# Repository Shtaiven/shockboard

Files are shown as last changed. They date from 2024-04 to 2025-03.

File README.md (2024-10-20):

# restive.engines Keyboards

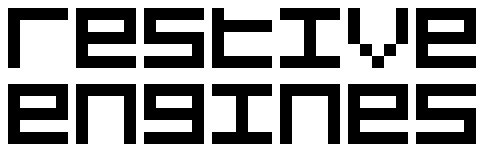
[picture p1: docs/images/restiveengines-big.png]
restiveengines_logo


## Introduction

This repository contains design and manufacturing files created by Steven Eisinger (@Shtaiven a.k.a. restive.engines). Everything you need to manufacture one of my keyboards can be found here, including pcbs, cases, and certain keycaps.

For keyboard firmware, please refer to my [ZMK config repo](https://github.com/Shtaiven/shockboard-zmk-config).

## Keyboards

### fairyboard

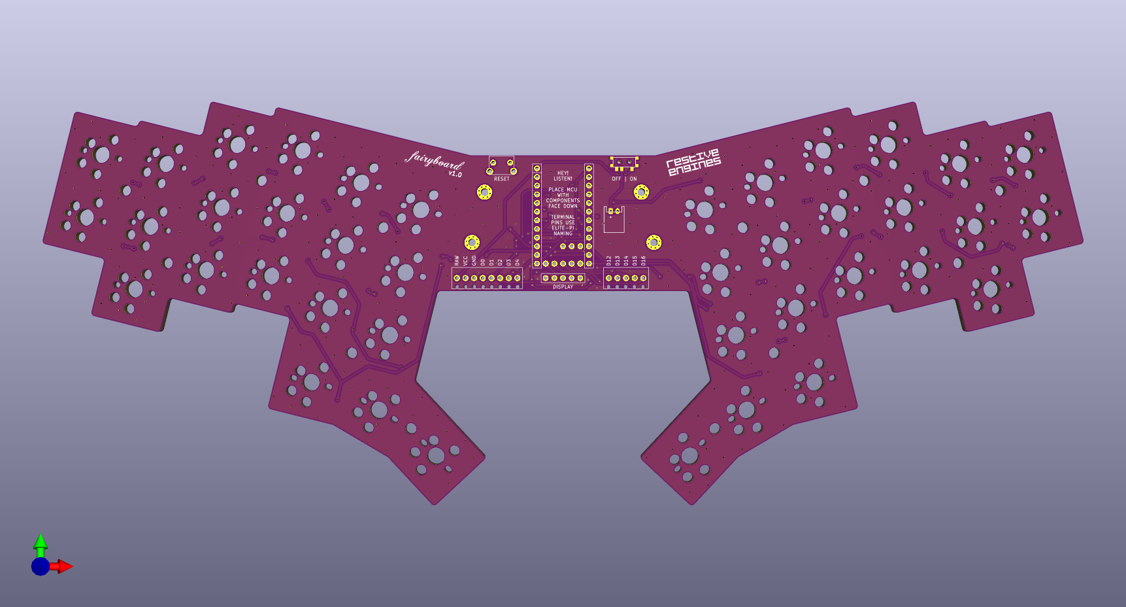
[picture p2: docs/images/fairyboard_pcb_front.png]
fairyboard pcb front


[Build guide](docs/fairyboard.md)

Designed in 2024. Made to address shortcomings and enhance ergonomics of the shockboard. Ergonomic column staggered keyboard extendable with custom modules using terminal blocks or headers. 14 degree rotation on each half. Compatible with MX, Choc v1, and Choc v2 switches.

### shockboard

shockboard_v1_assembled

[Build guide](docs/shockboard.md)

Designed in 2023. My first custom keyboard. Ergonomic column staggered keyboard with a number row, compatible with 1.25u thumb keys. 10 degree rotation on each half. Compatible with MX and Choc v1 switches.

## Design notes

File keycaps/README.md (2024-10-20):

# Printable Keycaps

This folder contains some printable keycaps

## Chicago stenographer

The `chicago_stenographer` directory contains kailh choc v1 keycaps originally designed by @pseudoku and modified by @sporkus and @infused-kim. The stls in this directory are the ones you need to print to get every possible keycap for the fairyboard. Print one of each.

See their original repositories for more info:

* [infused-kim's repo](https://github.com/infused-kim/kb_keycaps_chicago_stenographer)
* [sporkus's repo](https://github.com/sporkus/PseudoMakeMeKeyCapProfiles)
* [pseudoku's repo](https://github.com/pseudoku/PseudoMakeMeKeyCapProfiles)

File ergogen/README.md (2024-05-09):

# Ergogen configuration files

This folder contains the input and ouputs of ergogen to generate the shockboard layout.

## Note on compatibility

Ergogen v4.0.0 introduced breaking changes to configuration. Config files will only work with ergogen >= v4.0.0.

## Generating layouts

Due to the use of custom footprints, [ergogen](ergogen.xyz) must be installed locally and the online versions can't be used.
Before running anything below, ensure [npm](https://docs.npmjs.com/downloading-and-installing-node-js-and-npm) is installed on your system.

```shell
npm install -g ergogen@4
```

Output folders and are generated by calling ergogen in one of the revision folders e.g.

```shell
cd ergogen/shockboard_v1
ergogen .
```

The unrouted pcbs can then be found in the `output/pcbs` folder.

## Generating STLs

The ergogen config generates some cases in jscad format. Before converting these to STL files [jscad/cli](https://github.com/jscad/OpenJSCAD.org) must be installed.

```shell
npm install -g @jscad/cli
```

To generate the STLs, run the following from one of the revision folders (e.g. `shockboard_v1`)

```shell
for i in output/cases/*.jscad; do npx @jscad/cli@1 "$i" -of stla; done
```

The STLs can then be found in the `outpud/cases` folder.

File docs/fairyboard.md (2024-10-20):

# fairyboard

fairyboard pcb front
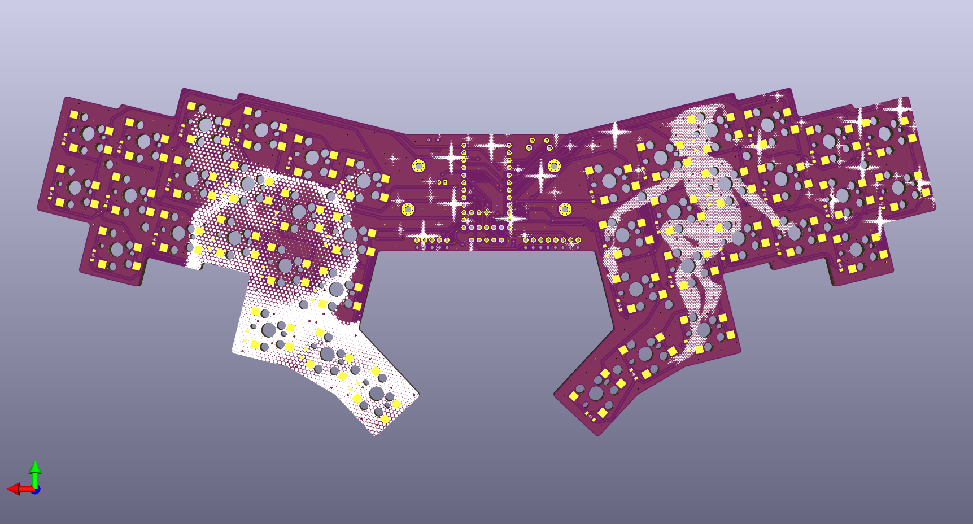
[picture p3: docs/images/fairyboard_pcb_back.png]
fairyboard pcb front


## Introduction

The fairyboard is a monoblock split columnar-staggered keyboard inspired by boards such as the corne, Lily58, Le Chiffre, and others. It is designed based on my own finger positions, with a thumb cluster that is comfortable for my smaller hands while resting in what I consider a neutral position. A monoblock design has been chosen easy portability and setup.

This is an iteration on my previous keyboard, [shockboard](shockboard.md). The changes include:

* a larger angle between the two halves (10mm -> 14mm)
* a larger distance between the two halves
* removed number row
* adjusted column stagger
* tighter thumb cluster
* rotated the choc v1 footprint relative to the MX one
* added choc v2 compatibility
* removed through-hole diode option
* compatibility with nice!view
* extendable with terminal blocks, headers, or through direct soldering to add future pointing devices

## Manufacturing

### PCB manufacture

See `pcbs/fairyboard_v1/fairyboard_v1.zip` for files containing pcb fabrication files for each keyboard revision. This zip file can be uploaded to JLCPCB for manufacturing.

## Assembly

### PCB BOM

* 1x fairyboard PCB
* 1x pro-micro, nice!nano, or elite-c pin compatible microcontroller (nice!nano recommended)
* Mill Max low profile sockets for your micricontroller (see [How do I socket a microcontroller?](https://docs.splitkb.com/hc/en-us/articles/360011263059-How-do-I-socket-a-microcontroller)) [[link](https://splitkb.com/products/mill-max-low-profile-sockets?variant=47060695646555)]
* 1x SKHLLCA010 footprint compatible button (side push) [[link](https://splitkb.com/products/reset-buttons?variant=42291963560195)]
* 1x MSK12C02 footprint compatible switch [[link](https://splitkb.com/products/wireless-controller-expansion-bundle?variant=42344261288195)]
* 40x 1N4148W diodes (SOD-123 surface mount or through-hole) [[link](https://splitkb.com/products/smd-diodes?variant=42283984027907)]
* 40x CPG151101S11 Kailh hotswap sockets for MX switches or CPG135001S30 Kailh hotswap sockets for choc switches [[link](https://keycapsss.com/keyboard-parts/parts/49/kailh-hotswap-pcb-sockets-10-pcs?number=KC10019_CHOC)]
* 40x MX or choc (v1 or v2) compatible keyboard switches [[link](https://splitkb.com/products/ambients-kailh-low-profile-choc-switches?variant=48116169277787)]
* 40x MX or choc (v1 or v2) compatible keycaps (you can [print your own](../keycaps))
* 1x nice!view display with male and female header pins (optional)
* 1x 301230 LiPo battery with 2-pin JST connector (optional for wireless microcontroller)
* 1x JST 2-pin jack (optional for wireless microcontroller) [[link](https://splitkb.com/products/wireless-controller-expansion-bundle?variant=42344261288195)]
* 1x 8-pin 2.54mm pitch terminal block (optional) [[link](https://nl.rs-online.com/web/p/pcb-terminal-blocks/2872357)]
* 1x 5-pin 2.54mm pitch terminal block (optional)

### PCB assembly

1. Solder the diodes to the back of the PCB (the side with the picture of the cat on it).
2. Solder the Kailh hotswap sockets to the back of the PCB. The hotswap sockets should be oriented such that the bumps fit through the holes and the metal contacts rest on the solder pads.
3. Solder Mill Max low profile female headers to the top side of the PCB in the middle for the microcontroller pins. See [here](https://docs.splitkb.com/hc/en-us/articles/360011263059-How-do-I-socket-a-microcontroller).
4. Socket your microcontroller such that the PCB will lie with its components face-down when attached to the PCB. The microcontroller will be attached from the top of the pcb, so match up the pin labels with those you see on the silkscreen there. See [here](https://docs.splitkb.com/hc/en-us/articles/360011263059-How-do-I-socket-a-microcontroller).
5. Solder the SKHLLCA010 button (reset button) to the top of the PCB to the left of the microcontroller.
6. Solder the MSK12C02 switch (power switch) to the top right corner of the PCB.
7. (optional) Solder the 2-pin JST connector to the top side of the board to the right of the microcontroller.
8. (optional) Solder the female headers for the OLED screen to the top side of the board below the microcontroller.
9. (optional) Install the battery into the JST connector and lay in down between the Mill Max headers where the microcontroller will be placed. Make sure that the red battery lead is connected to the left side of the JST jack (marked +) and the black lead is connected to the right side of the JST jack (marked -).
10. Insert the socketed microcontroller with the components facing away from you to the Mill Max sockets.
11. (optional) Insert the display with the pins on the bottom into the female headers.
12. (optional) Solder the terminal blocks to the holes to the bottom left and bottom right of the microcontroller.

### Case BOM

* 1x fairyboard case
* 12x 5mm (for choc) or 8mm (for MX) m2 spacers [[link](https://keycapsss.com/keyboard-parts/parts/62/m2-standoff-spacer-brass-round-10pcs?number=KC10031_5MM)]
* 24x 5mm m2 screws
* 4x 7mm m2 spacers for display cover (optional) [[link](https://keycapsss.com/keyboard-parts/parts/62/m2-standoff-spacer-brass-round-10pcs?number=KC10031_7mm)]
* 8x 5mm m2 screws for display cover (optional)

### Case Assembly

TODO

## Ordering

splitkb.com:

* 1x https://splitkb.com/products/m2-screws?variant=42396986999043
* 1x https://splitkb.com/products/smd-diodes?variant=42283984027907
* 1x https://splitkb.com/products/reset-buttons?variant=42291963560195
* 1x https://splitkb.com/products/wireless-controller-expansion-bundle?variant=42344261288195
* 2x https://splitkb.com/products/mill-max-low-profile-sockets?variant=47060695646555
* 1x https://splitkb.com/products/ambients-kailh-low-profile-choc-switches?variant=48116169277787

keycapsss.com:

* 5x https://keycapsss.com/keyboard-parts/parts/49/kailh-hotswap-pcb-sockets-10-pcs?number=KC10019_CHOC
* 1x https://keycapsss.com/keyboard-parts/parts/211/glidepoint-cirque-trackpad-tm040040-tm035035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
* 2x https://keycapsss.com/keyboard-parts/parts/62/m2-standoff-spacer-brass-round-10pcs?number=KC10031_5MM
* 2x https://keycapsss.com/keyboard-parts/parts/62/m2-standoff-spacer-brass-round-10pcs?number=KC10031_7mm

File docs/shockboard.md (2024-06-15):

# shockboard

Assembled shockboard

## Introduction

The shockboard is a monoblock split columnar-staggered keyboard inspired by boards such as the corne, Lily58, Le Chiffre, and others. It is designed based on my own finger positions, with a thumb cluster that is comfortable for my smaller hands while resting in what I consider a neutral position. A monoblock design has been chosen easy portability and setup.

## Manufacturing

### PCB manufacture

See `pcbs/shockboard_v1/shockboard_v1.zip` for files containing pcb fabrication files for each keyboard revision. This zip file can be uploaded to JLCPCB for manufacturing.

### Case manufacture

Only case files for MX switches are currently available in the cases folder.

To print the high profile MX case you will need:

* `cases/shockboard_v1/case_hipro_mx/case_hipro_mx_bottom.stl`
* `cases/shockboard_v1/case_hipro_mx/case_hipro_mx_top.stl`
* `cases/shockboard_v1/pcb_spacer.stl`

These files are provided in both `stl` and `3mf` variants, as well as split into left and right for smaller printers.

## Assembly

### PCB assembly

Materials:

* 1x shockboard PCB
* 1x pro-micro pin compatible microcontroller (nice!nano recommended)
* Mill Max low profile sockets for your micricontroller (see [How do I socket a microcontroller?](https://docs.splitkb.com/hc/en-us/articles/360011263059-How-do-I-socket-a-microcontroller))
* 1x SKHLACA010 footprint compatible button
* 1x MSK12C02 footprint compatible switch
* 52x 1N4148W diodes (SOD-123 surface mount or through-hole)
* 52x CPG151101S11 Kailh hotswap sockets
* 52x MX compatible keyboard switches
* 52x MX compatible keycaps
* 1x SSD1306 OLED display with male and female header pins (optional)
* 1x 301230 LiPo battery with 2-pin JST connector (optional for wireless microcontroller)
* 1x JST 2-pin jack (optional for wireless microcontroller)

Assembling the PCB:

1. Solder the diodes to the back of the PCB (the side with the picture of the cat on it).
2. Solder the Kailh hotswap sockets to the back of the PCB. The hotswap sockets should be oriented such that the bumps fit through the holes and the metal contacts rest on the solder pads.
3. Solder Mill Max low profile female headers to the top side of the PCB in the middle for the microcontroller pins. See [here](https://docs.splitkb.com/hc/en-us/articles/360011263059-How-do-I-socket-a-microcontroller).
4. Socket your microcontroller such that the PCB will lie with its components face-down when attached to the PCB. The microcontroller will be attached from the top of the pcb, so match up the pin labels with those you see on the silkscreen there. See [here](https://docs.splitkb.com/hc/en-us/articles/360011263059-How-do-I-socket-a-microcontroller).
5. Solder the SKHLACA010 button (reset button) to the top of the PCB to the left of the microcontroller.
6. Solder the MSK12C02 switch (power switch) to the top right corner of the PCB.
7. (optional) Solder the 2-pin JST connector to the top side of the board to the right of the microcontroller.
8. (optional) Solder the female headers for the OLED screen to the top side of the board below the microcontroller.
9. (optional) Install the battery into the JST connector and lay in down between the Mill Max headers where the microcontroller will be placed. Make sure that the red battery lead is connected to the left side of the JST jack (marked +) and the black lead is connected to the right side of the JST jack (marked -).
10. Insert the socketed microcontroller with the components faces away from you to the Mill Max sockets.
11. (optional) Insert the OLED display with the pins on the bottom into the female headers.

### Case assembly

Materials:

* 1x case bottom
* 1x case top
* 1x PCB spacer
* 8x m2x8mm screws
* 8x m2 heat-set inserts

Assembling the case:

1. Using a soldering iron, press in the heat-set inserts into the holes of the case bottom from the top-side such that the screws can be screwed in from the top.
2. Create a sandwich with the pieces in the following order from bottom to top:
    1. Case bottom
    2. PCB
    3. PCB spacer
    4. Case top
3. Align the 8 holes of all 4 pieces and screw in the 8 m2 screws from the top of the case until reasonable tight.
4. Insert your favorite switches and keycaps, upload your keyboard firmware, and enjoy!

## Firmware

This keyboard shield has been build with bluetooth-enabled pro-micro compatible boards in mind, like the [nice!nano](https://nicekeyboards.com/nice-nano/).

[ZMK](https://zmk.dev/) support has been added as an [external module](https://zmk.dev/docs/development/build-flash#building-with-external-modules) in my [zmk-config](https://github.com/Shtaiven/shockboard-zmk-config).

For an example of using this with the [miryoku](https://github.com/manna-harbour/miryoku/) layout, see [here](https://github.com/Shtaiven/miryoku_zmk/blob/master/.github/workflows/build.yml).

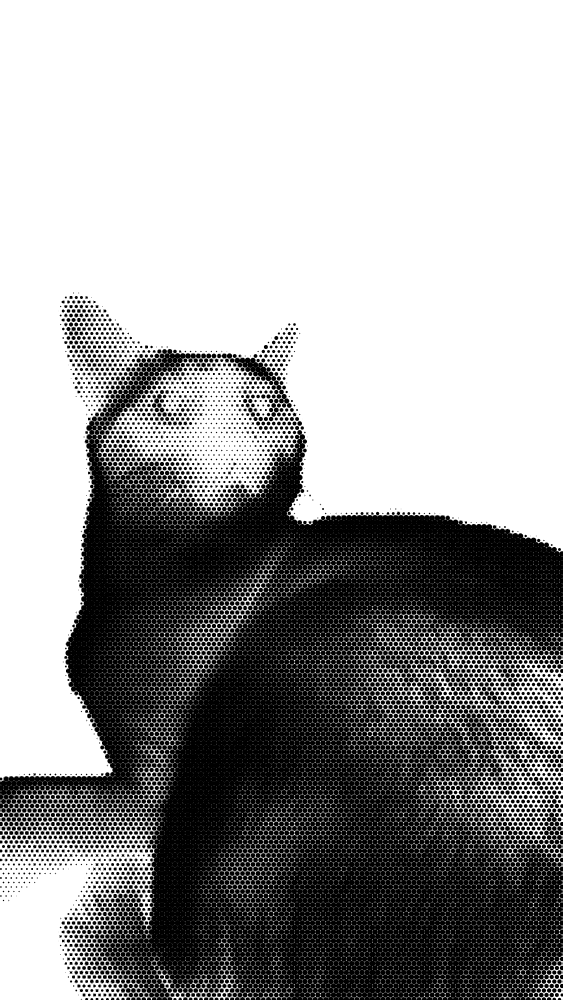
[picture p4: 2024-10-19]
pcbs/images/wumi-stare-halftone.png

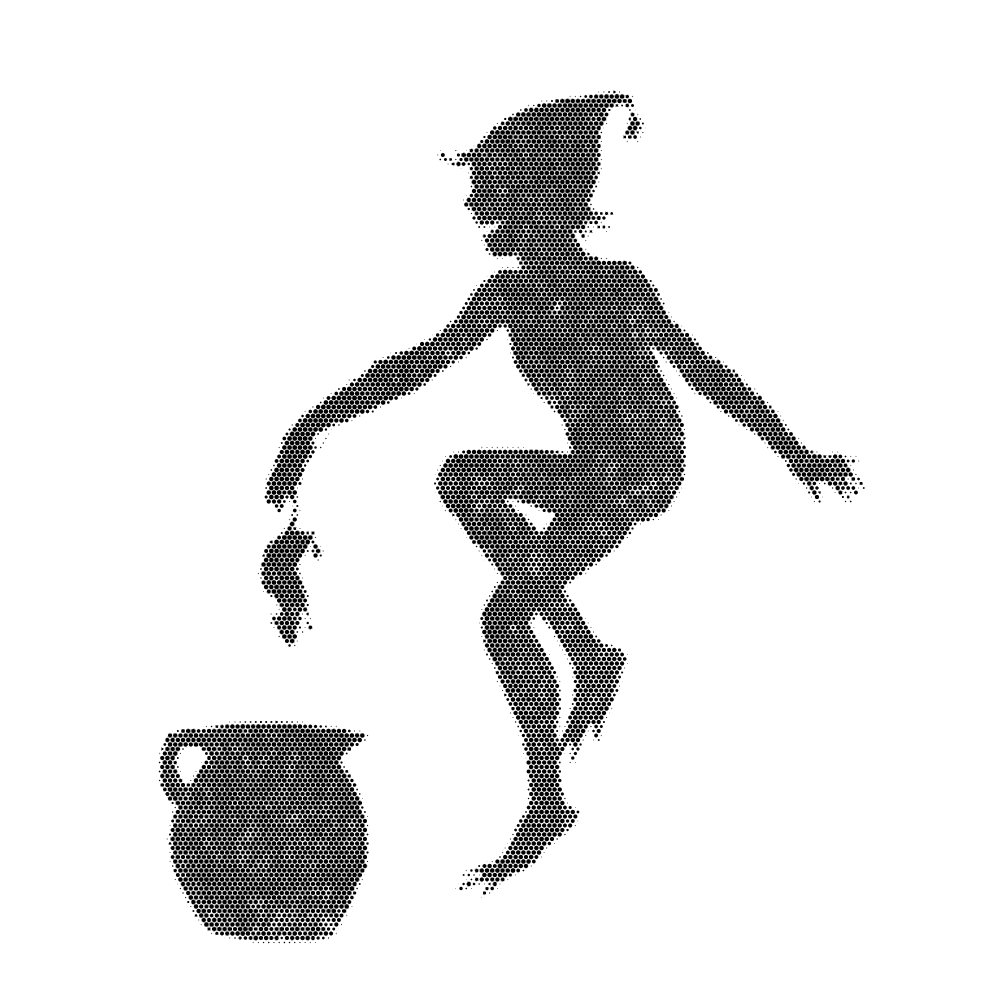
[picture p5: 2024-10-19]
pcbs/images/fairy-halftone.png

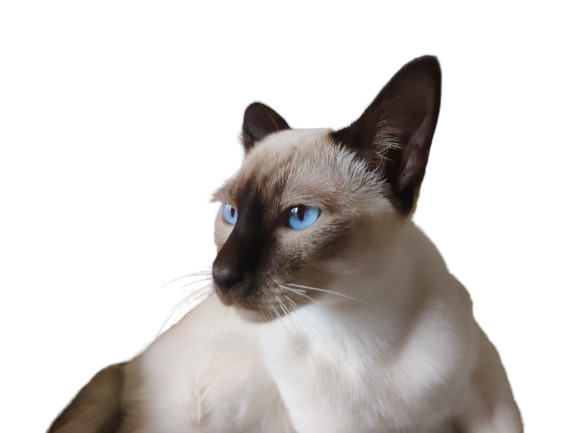
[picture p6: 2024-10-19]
pcbs/images/wumi-removebg.png

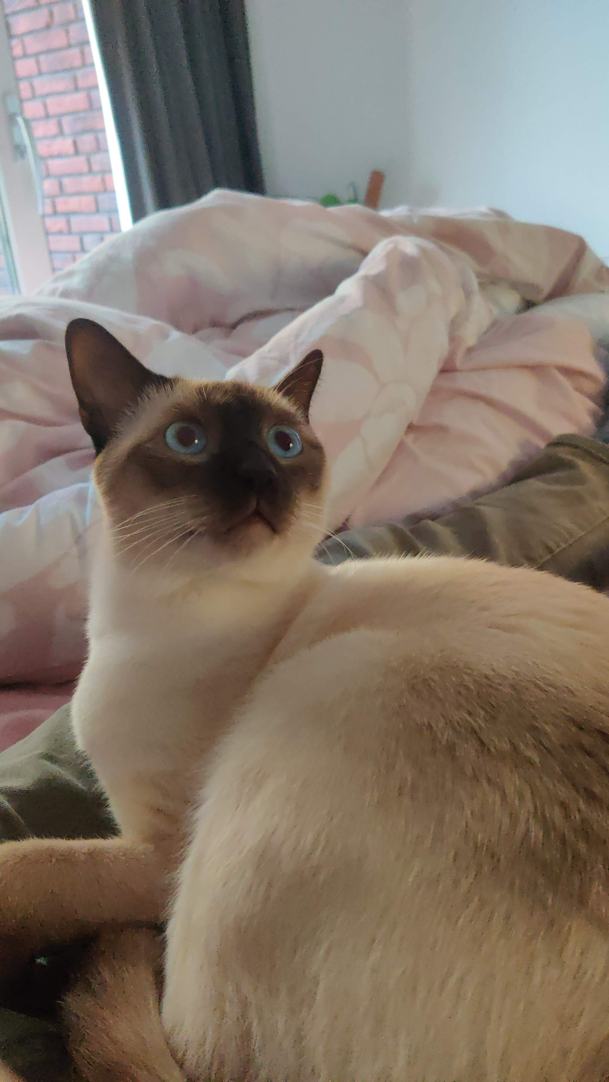
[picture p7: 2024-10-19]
pcbs/images/wumi-stare.jpeg

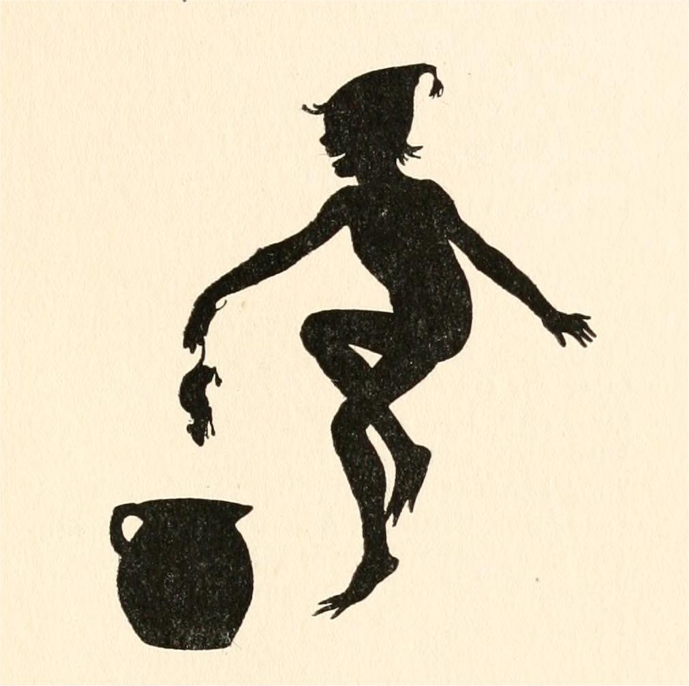
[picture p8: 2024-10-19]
pcbs/images/goble-book-of-fairy-poetry129two-fairies-in-a-garden-cfa38c.jpg

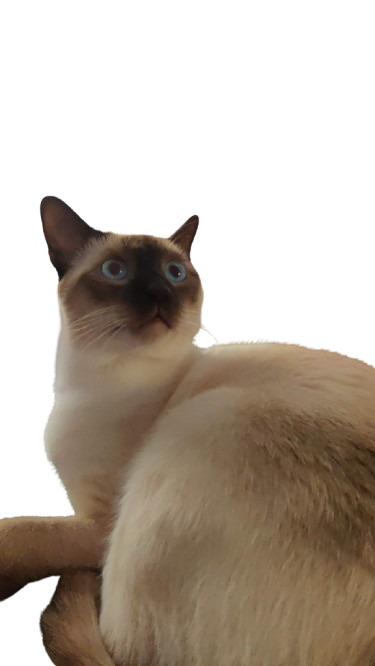
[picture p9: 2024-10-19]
pcbs/images/wumi-stare-removebg-preview.png

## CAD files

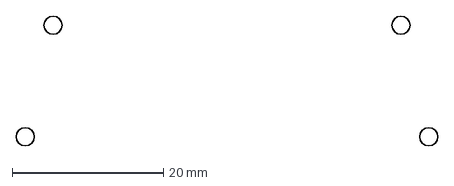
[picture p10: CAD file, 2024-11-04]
cases/fairyboard_v1/outlines/window_mounting_holes.dxf
55.8 x 17.1 mm

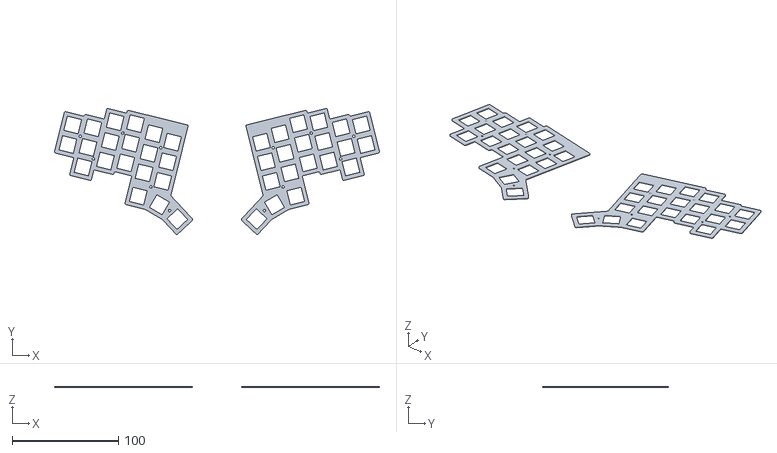
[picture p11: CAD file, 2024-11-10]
cases/fairyboard_v1/plate_case/top_plate_choc_v1.stl
305.7 x 118.5 x 1.20

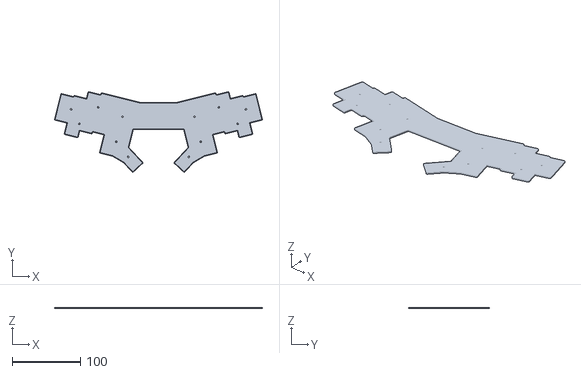
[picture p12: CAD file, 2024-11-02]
cases/fairyboard_v1/simple_case/bottom_case_mx.stl
305.7 x 118.5 x 2.00

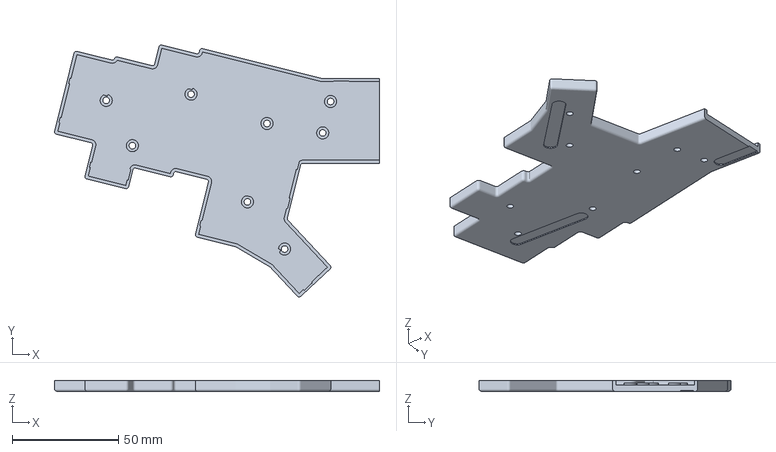
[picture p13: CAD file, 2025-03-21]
cases/fairyboard_v1/slim_case/bottom_case_lowpro_window_mounting_left.3mf
152.8 x 118.5 x 5.00 mm

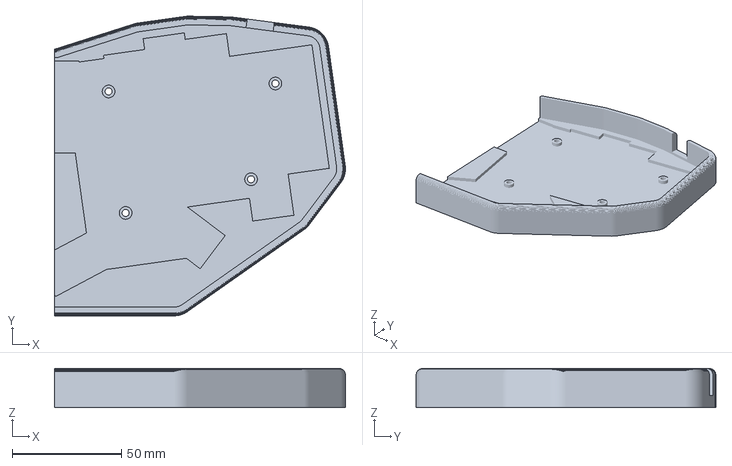
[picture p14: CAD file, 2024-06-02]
cases/shockboard_v1/case_hipro_mx/case_hipro_mx_bottom_right.3mf
133.0 x 137.0 x 18.0 mm

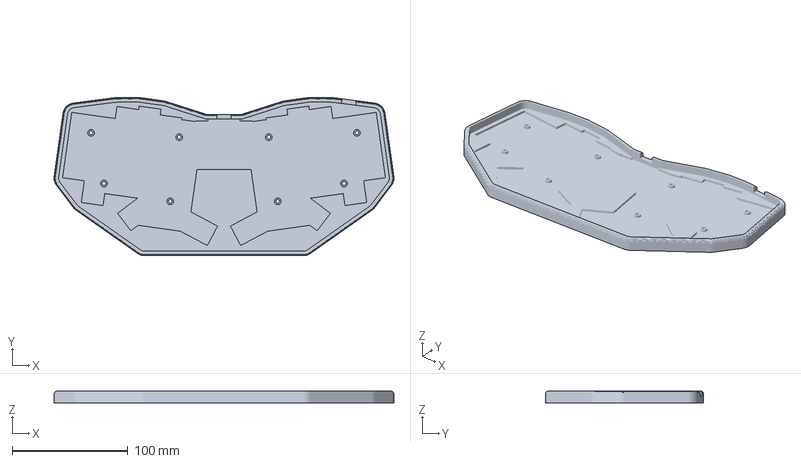
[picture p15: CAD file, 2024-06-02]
cases/shockboard_v1/case_lopro_mx/case_lopro_mx_bottom.3mf
293.9 x 137.0 x 10.6 mm

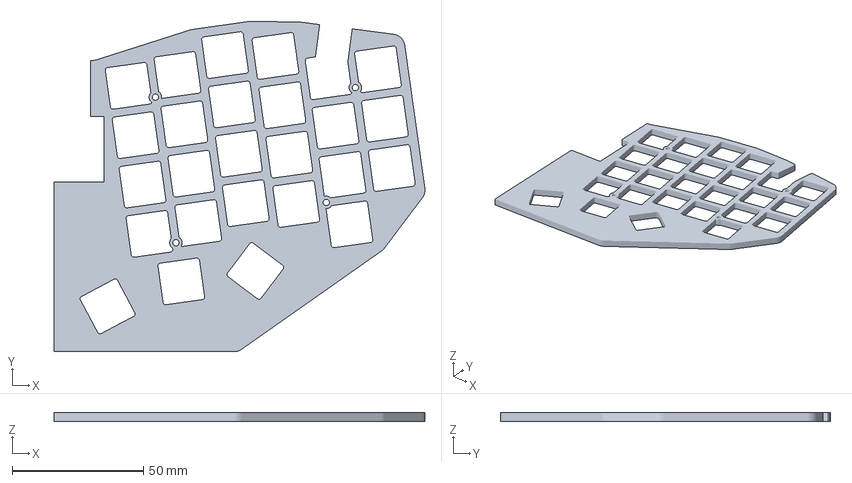
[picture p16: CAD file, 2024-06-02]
cases/shockboard_v1/pcb_spacer_right.3mf
141.4 x 126.0 x 3.50 mm

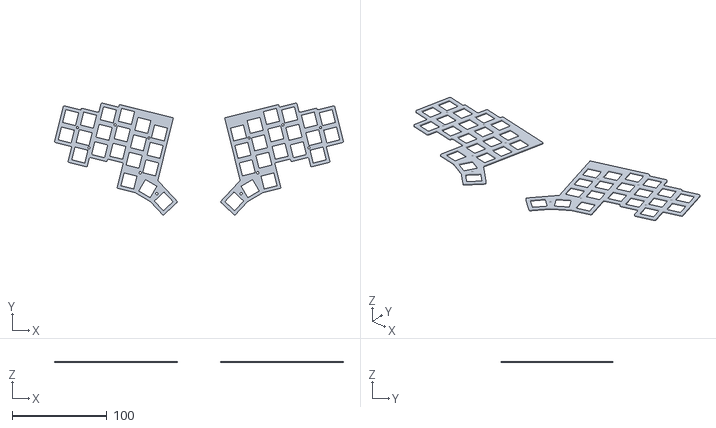
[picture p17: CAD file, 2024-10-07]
ergogen/fairyboard_v1/output/cases/plate_mx.stl
305.5 x 118.3 x 1.50

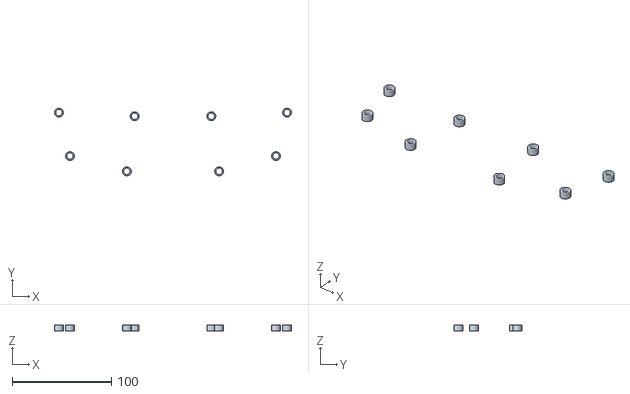
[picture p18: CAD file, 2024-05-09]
ergogen/shockboard_v1/output/cases/mounting_holes.stl
238.8 x 68.1 x 6.00

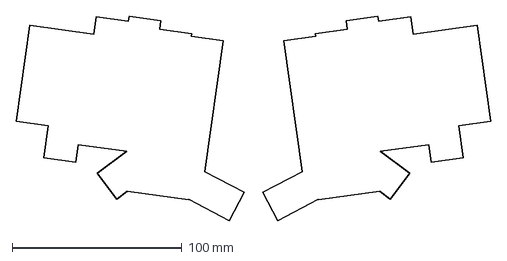
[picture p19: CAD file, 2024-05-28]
ergogen/shockboard_v1/output/outlines/keywell_mx.dxf
279.1 x 120.5 mm

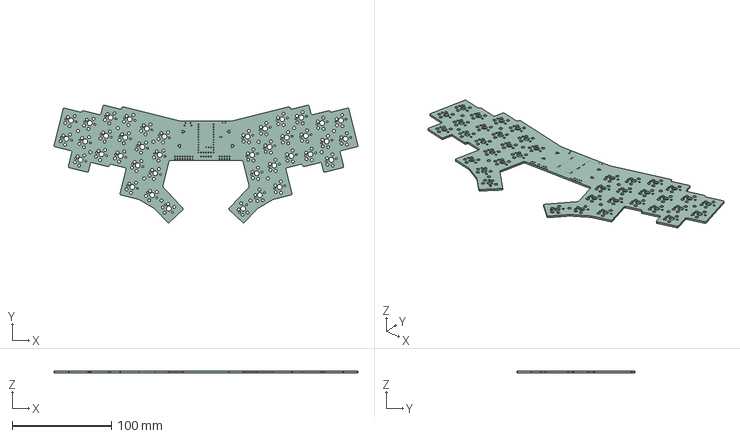
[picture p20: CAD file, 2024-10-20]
pcbs/fairyboard_v1/fairyboard.step
305.6 x 118.3 x 1.60 mm

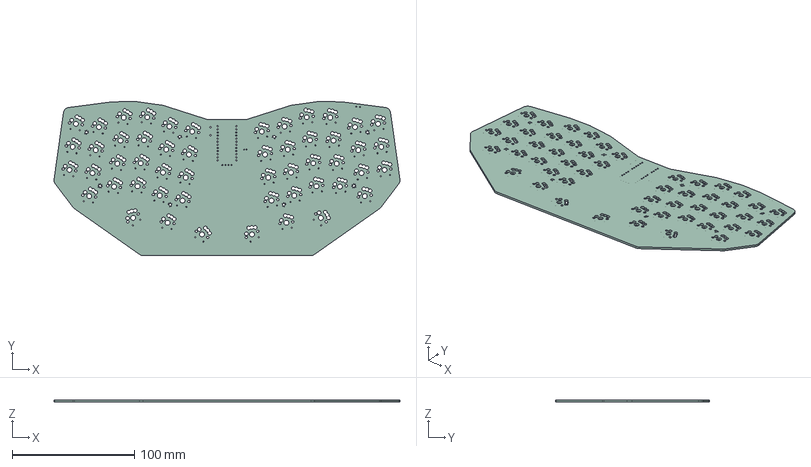
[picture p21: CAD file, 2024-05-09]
pcbs/shockboard_v1/shockboard.step
282.9 x 126.0 x 1.60 mm

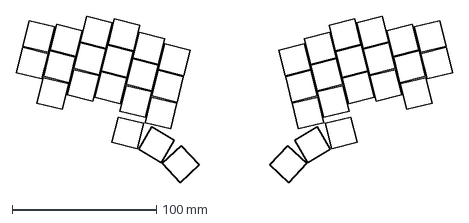
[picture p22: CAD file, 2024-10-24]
cases/fairyboard_v1/outlines/cutouts_extension.dxf
302.6 x 115.4 mm

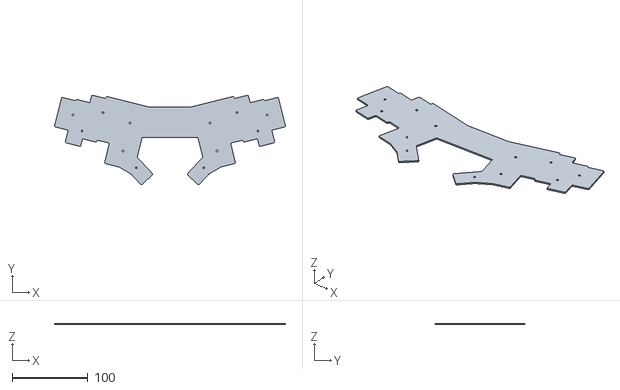
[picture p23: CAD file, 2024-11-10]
cases/fairyboard_v1/plate_case/bottom_plate.stl
305.7 x 118.5 x 1.50

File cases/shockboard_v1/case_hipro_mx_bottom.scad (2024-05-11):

use <shockboard_v1.scad>
use <../openscad-fillets/fillets3d.scad>

$fs = $preview ? 1 : 0.1;
$fa = $preview ? 3 : 0.1;
FILLET_STEPS = $preview ? 10 : 25;

module fillet_wall(wall_height, fillet_radius, fillet_steps, fillet_enable) {
    difference() {
        topFillet(wall_height, fillet_radius, fillet_steps, fillet_enable)
        linear_extrude(wall_height)
        case_outline();
        
        translate([0, 0, -1])
        linear_extrude(wall_height+2)
        board();
    };
}

module case_bottom_no_cutout(wall_height=18, fillet_radius=2.5, fillet_steps=50, fillet_enable=1) {
    difference() {
        union() {
            linear_extrude(2)
            case_outline();

            linear_extrude(4)
            mounting_holes_outer();
        }

        translate([0, 0, -1])
        linear_extrude(6)
        mounting_holes_inner();
    }

    fillet_wall(wall_height, fillet_radius, fillet_steps, fillet_enable);
}

module case_bottom(wall_height=18, fillet_radius=3, fillet_steps=20, fillet_enable=1) {
    difference() {
        case_bottom_no_cutout(wall_height, fillet_radius, fillet_steps, fillet_enable);
        
        translate([0, 0, 5.6])
        linear_extrude(15)
        usbc_cutout();
        
        translate([0, 0, 5.6])
        linear_extrude(15)
        battery_switch_cutout();
    }
}

case_bottom(fillet_steps=FILLET_STEPS);

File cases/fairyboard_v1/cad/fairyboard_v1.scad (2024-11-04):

/* [Corrective offset of imports (try Ctrl+T)] */
OFFSET_X = -210.46;
OFFSET_Y = 157.22;

/* [Paths] */
// (relative) path to the outline files
outline_dir = "../outlines/";

module board_connector_cutout() {
    translate([OFFSET_X, OFFSET_Y, 0])
    import(str(outline_dir, "board_connector_cutout.dxf"));
}

module board_connector() {
    translate([OFFSET_X, OFFSET_Y, 0])
    import(str(outline_dir,"board_connector.dxf"));
}

module board_connector_extended() {
    translate([OFFSET_X, OFFSET_Y, 0])
    import(str(outline_dir,"board_connector_extended.dxf"));
}

module board() {
    translate([OFFSET_X, OFFSET_Y, 0])
    import(str(outline_dir,"board.dxf"));
}

module board_raw() {
    translate([OFFSET_X, OFFSET_Y, 0])
    import(str(outline_dir,"board_raw.dxf"));
}

module case_outline() {
    translate([OFFSET_X, OFFSET_Y, 0])
    import(str(outline_dir,"case_outline.dxf"));
}

module cutouts_choc() {
    translate([OFFSET_X, OFFSET_Y, 0])
    import(str(outline_dir,"cutouts_choc.dxf"));
}

module cutouts_mx() {
    translate([OFFSET_X, OFFSET_Y, 0])
    import(str(outline_dir,"cutouts_mx.dxf"));
}

module cutouts_extension() {
    translate([OFFSET_X, OFFSET_Y, 0])
    import(str(outline_dir,"cutouts_extension.dxf"));
}

module demo() {
    translate([OFFSET_X, OFFSET_Y, 0])
    import(str(outline_dir,"demo.dxf"));
}

module m2_holes() {
    translate([OFFSET_X, OFFSET_Y, 0])
    import(str(outline_dir,"m2_holes.dxf"));
}

module m2_spacers() {
    translate([OFFSET_X, OFFSET_Y, 0])
    import(str(outline_dir,"m2_spacers.dxf"));
}

module pcb_outline() {
    // this is exported directly from the pcb unlike the others in this file
    translate([OFFSET_X-1.272928, OFFSET_Y+1.45, 0]) // offsets compared in inkscape
    fill() // requires openscad development version
    import(str(outline_dir,"pcb_outline.dxf"));
}

module pcb_edge_support() {
    translate([OFFSET_X, OFFSET_Y, 0])
    import(str(outline_dir,"pcb_edge_support.dxf"));
}

module plate_choc() {
    translate([OFFSET_X, OFFSET_Y, 0])
    import(str(outline_dir,"plate_choc.dxf"));
}

module plate_mx() {
    translate([OFFSET_X, OFFSET_Y, 0])
    import(str(outline_dir,"plate_mx.dxf"));
}

module plate_outline() {
    translate([OFFSET_X, OFFSET_Y, 0])
    import(str(outline_dir,"plate_outline.dxf"));
}

module wall() {
    translate([OFFSET_X, OFFSET_Y, 0])
    import(str(outline_dir,"wall.dxf"));
}

module window_mounting_holes() {
    translate([OFFSET_X, OFFSET_Y, 0])
    import(str(outline_dir,"window_mounting_holes.dxf"));
}

pcb_outline();
*board();

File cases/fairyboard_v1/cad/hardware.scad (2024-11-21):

module scuf_feet_outline() {
    width = 36;
    diameter = 6;
    
    hull() {
        translate([width/2, 0, 0])
        circle(d=diameter);
        translate([-width/2, 0, 0])
        circle(d=diameter);
    }
    
}

module scuf_feet_detent() {
    translate([0, 0, 0.5])
    mirror([0, 0, 1])
    linear_extrude(0.5, convexity=5, scale=[42.2/42, 6.2/6]) // 0.1mm chamfer
    scuf_feet_outline();
}

module choc_v1_keycap_spacer(depth=0.6) {
    hole_size = [1.4, 3.2];
    x_distance = 5.7;
    fillet_radius = 2;
    $fn=8;
    linear_extrude(depth, convexity=5)
    difference() {
        offset(delta=-fillet_radius)
        offset(r=fillet_radius)
        square([x_distance+hole_size.x+2, hole_size.y+2], center = true);
        
        translate([x_distance/2, 0, 0])
        square(hole_size, center = true);
        
        translate([-x_distance/2, 0, 0])
        square(hole_size, center = true);
    }
}

//scuf_feet_detent();
choc_v1_keycap_spacer();

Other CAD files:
cases/fairyboard_v1/slim_case/bottom_case_lowpro_window_mounting_right.3mf
cases/shockboard_v1/case_hipro_mx/case_hipro_mx_top_right.3mf
cases/shockboard_v1/case_lopro_mx/case_lopro_mx_top.3mf
cases/shockboard_v1/cad/hardware.scad
cases/fairyboard_v1/cad/assembly.scad
cases/fairyboard_v1/cad/bottom_case.scad
cases/fairyboard_v1/cad/center_window.scad
cases/fairyboard_v1/cad/top_case.scad
cases/fairyboard_v1/cad/util.scad
cases/fairyboard_v1/outlines/board.dxf
cases/fairyboard_v1/outlines/board_connector.dxf
cases/fairyboard_v1/outlines/board_connector_cutout.dxf
cases/fairyboard_v1/outlines/board_connector_extended.dxf
cases/fairyboard_v1/outlines/board_raw.dxf
cases/fairyboard_v1/outlines/case_outline.dxf
cases/fairyboard_v1/outlines/cutouts_choc.dxf
cases/fairyboard_v1/outlines/cutouts_mx.dxf
cases/fairyboard_v1/outlines/m2_holes.dxf
cases/fairyboard_v1/outlines/m2_spacers.dxf
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

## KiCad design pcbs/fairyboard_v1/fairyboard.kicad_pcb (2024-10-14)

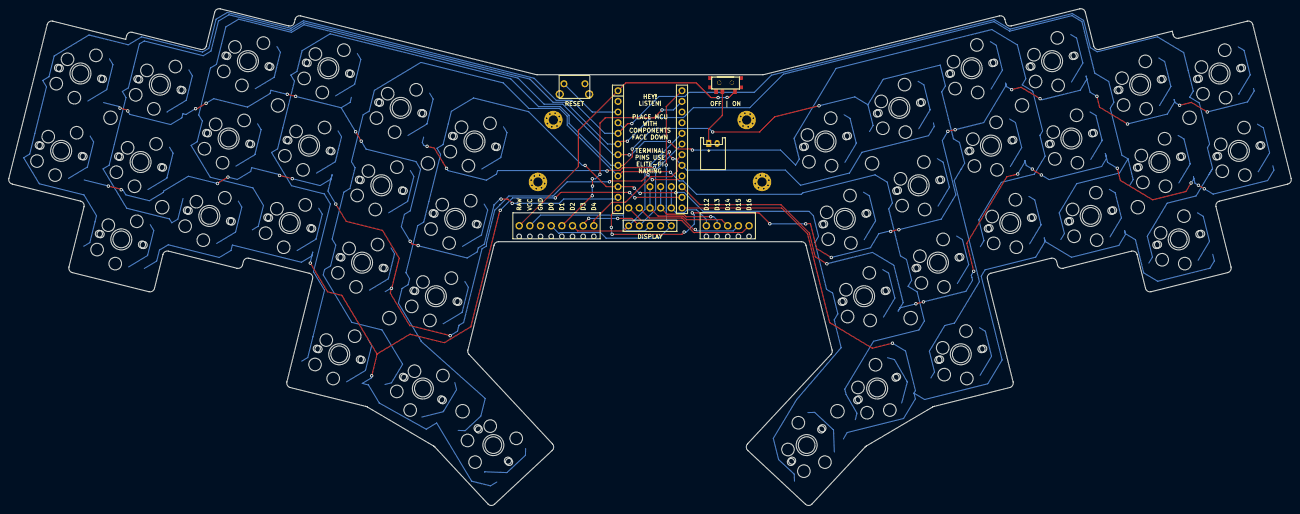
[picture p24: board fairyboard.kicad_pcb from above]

Board: 2 copper layers, 305.6 x 118.3 mm, 142 parts (0 on the bottom side), 60 nets.

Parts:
D1, D2, D3, D4, D5, D6, D7, D8, D9, D10, D11, D12, D13, D14, D15, D16, D17, D18, D19, D20, D21, D22, D23, D24, D25, D26, D27, D28, D29, D30, D31, D32, D33, D34, D35, D36, D37, D38, D39, D40: SmtDiode
DISP1: display_nice_view
JST1: JST_PH_S2B-PH-K_02x2.00mm_Angled
RST1: reset_switch_tht_side
S1, S2, S3, S4, S5, S6, S7, S8, S9, S10, S11, S12, S13, S14, S15, S16, S17, S18, S19, S20, S21, S22, S23, S24, S25, S26, S27, S28, S29, S30, S31, S32, S33, S34, S35, S36, S37, S38, S39, S40: MX
S41, S42, S43, S44, S45, S46, S47, S48, S49, S50, S51, S52, S53, S54, S55, S56, S57, S58, S59, S60, S61, S62, S63, S64, S65, S66, S67, S68, S69, S70, S71, S72, S73, S74, S75, S76, S77, S78, S79, S80: PG1350
T1: SPDT_C128955
TERMINAL1: terminal_block_8
TERMINAL2: terminal_block_5
_2, _3, _4, _5, _6, _7, _8, _9, _10, _11, _12, _13: SpacerHole_3.2mm_M2_Pad_Via
_14, _15, _16, _17: MountingHole_2.2mm_M2_Pad_Via

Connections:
B+: JST1.1, T1.2
COL1: S1.1, S2.1, S3.1, S21.1, S22.1, S23.1, S41.2, S42.2, S43.2, S61.2, S62.2, S63.2
COL2: S4.1, S5.1, S6.1, S24.1, S25.1, S26.1, S44.2, S45.2, S46.2, S64.2, S65.2, S66.2
COL3: S7.1, S8.1, S9.1, S27.1, S28.1, S29.1, S37.1, S47.2, S48.2, S49.2, S67.2, S68.2, S69.2, S77.2
COL4: S10.1, S11.1, S18.1, S30.1, S31.1, S34.1, S38.1, S50.2, S51.2, S58.2, S70.2, S71.2, S74.2, S78.2
COL5: S12.1, S13.1, S14.1, S19.1, S32.1, S33.1, S39.1, S52.2, S53.2, S54.2, S59.2, S72.2, S73.2, S79.2
COL6: S15.1, S16.1, S17.1, S20.1, S35.1, S36.1, S40.1, S55.2, S56.2, S57.2, S60.2, S75.2, S76.2, S80.2
D0: DISP1.5, TERMINAL1.4
D2: DISP1.1, TERMINAL1.6
D3: DISP1.2, TERMINAL1.7
GND: DISP1.4, JST1.2, RST1.1, TERMINAL1.3
RAW: T1.1, TERMINAL1.1
ROW1: D14.1, D17.1, D34.1, D37.1
ROW2: D2.1, D5.1, D8.1, D11.1, D13.1, D16.1
ROW3: D1.1, D4.1, D7.1, D10.1, D12.1, D15.1
ROW4: D3.1, D6.1, D9.1, D18.1, D19.1, D20.1
ROW5: D22.1, D25.1, D28.1, D31.1, D33.1, D36.1
ROW6: D21.1, D24.1, D27.1, D30.1, D32.1, D35.1
ROW7: D23.1, D26.1, D29.1, D38.1, D39.1, D40.1
VCC: DISP1.3, TERMINAL1.2
index_bottom: D12.2, S12.2, S52.1
index_home: D13.2, S13.2, S53.1
index_top: D14.2, S14.2, S54.1
inner_bottom: D15.2, S15.2, S55.1
inner_home: D16.2, S16.2, S56.1
inner_thumb: D20.2, S20.2, S60.1
inner_top: D17.2, S17.2, S57.1
middle_bottom: D9.2, S9.2, S49.1
middle_home: D10.2, S10.2, S50.1
middle_thumb: D19.2, S19.2, S59.1
middle_top: D11.2, S11.2, S51.1
mirror_index_bottom: D32.2, S32.2, S72.1
mirror_index_home: D33.2, S33.2, S73.1
mirror_index_top: D34.2, S34.2, S74.1
mirror_inner_bottom: D35.2, S35.2, S75.1
mirror_inner_home: D36.2, S36.2, S76.1
mirror_inner_thumb: D40.2, S40.2, S80.1
mirror_inner_top: D37.2, S37.2, S77.1
mirror_middle_bottom: D29.2, S29.2, S69.1
mirror_middle_home: D30.2, S30.2, S70.1
mirror_middle_thumb: D39.2, S39.2, S79.1
mirror_middle_top: D31.2, S31.2, S71.1
mirror_outer_home: D21.2, S21.2, S61.1
mirror_outer_thumb: D38.2, S38.2, S78.1
mirror_outer_top: D22.2, S22.2, S62.1
mirror_pinky_bottom: D23.2, S23.2, S63.1
mirror_pinky_home: D24.2, S24.2, S64.1
mirror_pinky_top: D25.2, S25.2, S65.1
mirror_ring_bottom: D26.2, S26.2, S66.1
mirror_ring_home: D27.2, S27.2, S67.1
mirror_ring_top: D28.2, S28.2, S68.1
outer_home: D1.2, S1.2, S41.1
outer_thumb: D18.2, S18.2, S58.1
outer_top: D2.2, S2.2, S42.1
pinky_bottom: D3.2, S3.2, S43.1
pinky_home: D4.2, S4.2, S44.1
pinky_top: D5.2, S5.2, S45.1
ring_bottom: D6.2, S6.2, S46.1
ring_home: D7.2, S7.2, S47.1
ring_top: D8.2, S8.2, S48.1

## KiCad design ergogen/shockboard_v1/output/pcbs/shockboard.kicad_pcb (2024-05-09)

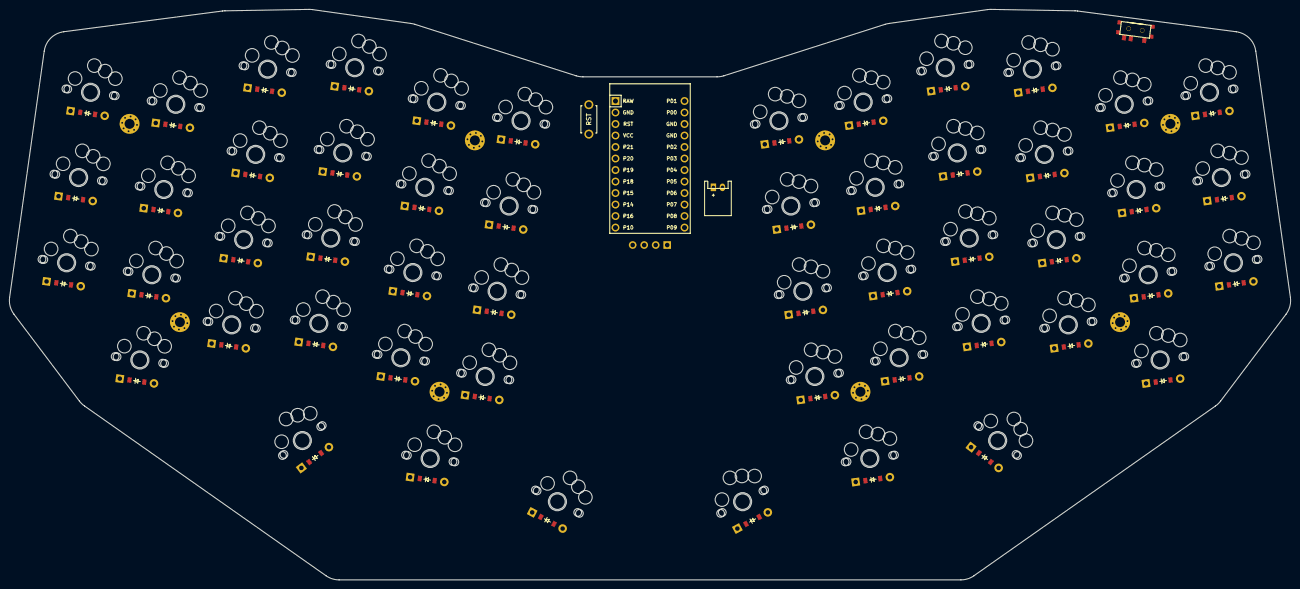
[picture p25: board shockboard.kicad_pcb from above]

Board: 2 copper layers, 282.9 x 126.0 mm, 169 parts (0 on the bottom side), 75 nets, no tracks yet.

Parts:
D1, D2, D3, D4, D5, D6, D7, D8, D9, D10, D11, D12, D13, D14, D15, D16, D17, D18, D19, D20, D21, D22, D23, D24, D25, D26, D27, D28, D29, D30, D31, D32, D33, D34, D35, D36, D37, D38, D39, D40, D41, D42, D43, D44, D45, D46, D47, D48, D49, D50, D51, D52: ComboDiode
JST1: JST_PH_S2B-PH-K_02x2.00mm_Angled
MCU1: ProMicro
OLED1: OLED; OLED_headers
RST1: reset_switch_tht_top
S1, S2, S3, S4, S5, S6, S7, S8, S9, S10, S11, S12, S13, S14, S15, S16, S17, S18, S19, S20, S21, S22, S23, S24, S25, S26, S27, S28, S29, S30, S31, S32, S33, S34, S35, S36, S37, S38, S39, S40, S41, S42, S43, S44, S45, S46, S47, S48, S49, S50, S51, S52: MX
S53, S54, S55, S56, S57, S58, S59, S60, S61, S62, S63, S64, S65, S66, S67, S68, S69, S70, S71, S72, S73, S74, S75, S76, S77, S78, S79, S80, S81, S82, S83, S84, S85, S86, S87, S88, S89, S90, S91, S92, S93, S94, S95, S96, S97, S98, S99, S100, S101, S102, S103, S104: PG1350
T1: SPDT_C128955
_1, _2, _3, _4, _5, _6, _7, _8: MountingHole_2.2mm_M2_Pad_Via

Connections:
B+: JST1.1, T1.2
GND: JST1.2, MCU1.2, MCU1.15, MCU1.16, OLED1.1, RST1.2
P0: D27.1, D31.1, D35.1, D39.1, D43.1, D47.1, MCU1.14
P1: D30.1, D34.1, D38.1, D42.1, D46.1, MCU1.13
P2: MCU1.17, OLED1.4
P3: MCU1.18, OLED1.3
P4: D28.1, D32.1, D36.1, D40.1, D44.1, D48.1, MCU1.19
P5: D29.1, D33.1, D37.1, D41.1, D45.1, D49.1, MCU1.20
P6: D50.1, D51.1, D52.1, MCU1.21
P7: MCU1.22, S12.1, S13.1, S14.1, S15.1, S24.1, S38.1, S39.1, S40.1, S41.1, S50.1, S64.1, S65.1, S66.1, S67.1, S76.1, S90.1, S91.1, S92.1, S93.1, S102.1
P8: MCU1.23, S16.1, S17.1, S18.1, S19.1, S25.1, S42.1, S43.1, S44.1, S45.1, S51.1, S68.1, S69.1, S70.1, S71.1, S77.1, S94.1, S95.1, S96.1, S97.1, S103.1
P9: MCU1.24, S20.1, S21.1, S22.1, S23.1, S26.1, S46.1, S47.1, S48.1, S49.1, S52.1, S72.1, S73.1, S74.1, S75.1, S78.1, S98.1, S99.1, S100.1, S101.1, S104.1
P10: MCU1.12, S8.1, S9.1, S10.1, S11.1, S34.1, S35.1, S36.1, S37.1, S60.1, S61.1, S62.1, S63.1, S86.1, S87.1, S88.1, S89.1
P14: MCU1.10, S1.1, S2.1, S3.1, S27.1, S28.1, S29.1, S53.1, S54.1, S55.1, S79.1, S80.1, S81.1
P15: D24.1, D25.1, D26.1, MCU1.9
P16: MCU1.11, S4.1, S5.1, S6.1, S7.1, S30.1, S31.1, S32.1, S33.1, S56.1, S57.1, S58.1, S59.1, S82.1, S83.1, S84.1, S85.1
P18: D3.1, D7.1, D11.1, D15.1, D19.1, D23.1, MCU1.8
P19: D2.1, D6.1, D10.1, D14.1, D18.1, D22.1, MCU1.7
P20: D1.1, D5.1, D9.1, D13.1, D17.1, D21.1, MCU1.6
P21: D4.1, D8.1, D12.1, D16.1, D20.1, MCU1.5
RAW: MCU1.1, T1.1
RST: MCU1.3, RST1.1
VCC: MCU1.4, OLED1.2
index_bottom: D16.2, S16.2, S68.2
index_home: D17.2, S17.2, S69.2
index_num: D19.2, S19.2, S71.2
index_top: D18.2, S18.2, S70.2
inner_bottom: D20.2, S20.2, S72.2
inner_home: D21.2, S21.2, S73.2
inner_num: D23.2, S23.2, S75.2
inner_thumb: D26.2, S26.2, S78.2
inner_top: D22.2, S22.2, S74.2
middle_bottom: D12.2, S12.2, S64.2
middle_home: D13.2, S13.2, S65.2
middle_num: D15.2, S15.2, S67.2
middle_thumb: D25.2, S25.2, S77.2
middle_top: D14.2, S14.2, S66.2
mirror_index_bottom: D42.2, S42.2, S94.2
mirror_index_home: D43.2, S43.2, S95.2
mirror_index_num: D45.2, S45.2, S97.2
mirror_index_top: D44.2, S44.2, S96.2
mirror_inner_bottom: D46.2, S46.2, S98.2
mirror_inner_home: D47.2, S47.2, S99.2
mirror_inner_num: D49.2, S49.2, S101.2
mirror_inner_thumb: D52.2, S52.2, S104.2
mirror_inner_top: D48.2, S48.2, S100.2
mirror_middle_bottom: D38.2, S38.2, S90.2
mirror_middle_home: D39.2, S39.2, S91.2
mirror_middle_num: D41.2, S41.2, S93.2
mirror_middle_thumb: D51.2, S51.2, S103.2
mirror_middle_top: D40.2, S40.2, S92.2
mirror_outer_home: D27.2, S27.2, S79.2
mirror_outer_num: D29.2, S29.2, S81.2
mirror_outer_thumb: D50.2, S50.2, S102.2
mirror_outer_top: D28.2, S28.2, S80.2
mirror_pinky_bottom: D30.2, S30.2, S82.2
mirror_pinky_home: D31.2, S31.2, S83.2
mirror_pinky_num: D33.2, S33.2, S85.2
mirror_pinky_top: D32.2, S32.2, S84.2
mirror_ring_bottom: D34.2, S34.2, S86.2
mirror_ring_home: D35.2, S35.2, S87.2
mirror_ring_num: D37.2, S37.2, S89.2
mirror_ring_top: D36.2, S36.2, S88.2
outer_home: D1.2, S1.2, S53.2
outer_num: D3.2, S3.2, S55.2
outer_thumb: D24.2, S24.2, S76.2
outer_top: D2.2, S2.2, S54.2
pinky_bottom: D4.2, S4.2, S56.2
pinky_home: D5.2, S5.2, S57.2
pinky_num: D7.2, S7.2, S59.2
pinky_top: D6.2, S6.2, S58.2
ring_bottom: D8.2, S8.2, S60.2
ring_home: D9.2, S9.2, S61.2
ring_num: D11.2, S11.2, S63.2
ring_top: D10.2, S10.2, S62.2

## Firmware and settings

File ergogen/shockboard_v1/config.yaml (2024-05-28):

# meta:
#   engine: 4.0.5
#   version: 1.0
#   author: Steven Eisinger

# V2 TODOS:
#   TODO: Add pins for 35mm/40mm cirque trackpad (external footprint)
#   TODO: Add pins for nice!view
#   TODO: Widen mounting holes to accomodate a full m2 spacer through the pcb?
#   TODO: move inner thumb keys inward
#   TODO: Larger split rotation (15 degrees?)
#   TODO: Move reset button (maybe a sidways one)
#   TODO: Bigger battery slide switch
#   TODO: Standoff location for Lily58-compatible acrylic screen window
#   TODO: Wire key matrix to use 5x9 pins (up to 54) instead of 5x10 (up to 60)
#   TODO: Leave P1 free for nice!view CS pin
#   TODO: Widen keywell for middle thumb key to accomodate 1u-1.5u-1u configuration

#
# Define unit constants
#
units:
  # split
  SPLIT_ROTATION: -8
  SPLIT_DISTANCE: 67.5

  # column stagger
  COLUMN_RING_STAGGER: 10.5
  COLUMN_MIDDLE_STAGGER: 3
  COLUMN_INDEX_STAGGER: -5
  COLUMN_INNER_STAGGER: -1.5

  # thumbfan common
  THUMBFAN_ROT: 0
  THUMBFAN_X: 0.5u
  THUMBFAN_Y: -1.375u

  # thumbfan outer
  THUMBFAN_OUTER_ROT: 45
  THUMBFAN_OUTER_X: -0.5u
  THUMBFAN_OUTER_Y: 0

  # thumbfan middle
  THUMBFAN_MIDDLE_ROT: 0
  THUMBFAN_MIDDLE_X: 0
  THUMBFAN_MIDDLE_Y: 0

  # thumbfan inner
  THUMBFAN_INNER_ROT: 0
  THUMBFAN_INNER_X: 0.4u
  THUMBFAN_INNER_Y: 0.05u

  # screw radius
  SCREW_SIZE: 1.6
  SCREW_BORDER: SCREW_SIZE + 1.3
  STANDOFF_SIZE: 4

  # case parameters
  BOTTOM_THICKNESS: 2
  WALL_THICKNESS: 5

  # plate parameters
  PLATE_THICKNESS: 1.5
  PLATE_EXTENSION: 1

#
# Define key locations
#
# matrix: finger matrix (excluding thumbs)
# thumbfan: thumb keys
#
points:
  zones:
    matrix:
     # Fix placement on KiCAD sheet.
      anchor:
        shift: [100, -130]
      columns:
        outer:
          key:
            column_net: P14
          rows:
            bottom.skip: true
        pinky:
          key:
            column_net: P16
        ring:
          key:
            stagger: COLUMN_RING_STAGGER
            column_net: P10
        middle:
          key:
            stagger: COLUMN_MIDDLE_STAGGER
            column_net: P7
        index:
          key:
            stagger: COLUMN_INDEX_STAGGER
            column_net: P8
        inner:
          key:
            stagger: COLUMN_INNER_STAGGER
            column_net: P9
      rows:
        bottom:
          row_net: P21
          mirror.row_net: P1
        home:
          row_net: P20
          mirror.row_net: P0
        top:
          row_net: P19
          mirror.row_net: P4
        num:
          row_net: P18
          mirror.row_net: P5
    thumbfan:
      anchor:
        ref: matrix_middle_bottom
        rotate: THUMBFAN_ROT
        shift: [THUMBFAN_X, THUMBFAN_Y]
      columns:
        outer:
          key:
            rotate: THUMBFAN_OUTER_ROT
            shift: [THUMBFAN_OUTER_X, THUMBFAN_OUTER_Y]
            width: 1.25u
            column_net: P7
        middle:
          key:
            rotate: THUMBFAN_MIDDLE_ROT
            shift: [THUMBFAN_MIDDLE_X, THUMBFAN_MIDDLE_Y]
            width: 1.25u
            column_net: P8
        inner:
          key:
            splay: -20
            origin: [-0.5u, -0.5u]
            rotate: THUMBFAN_INNER_ROT
            shift: [THUMBFAN_INNER_X, THUMBFAN_INNER_Y]
            width: 1.25u
            column_net: P9
      rows:
        thumb:
          row_net: P15
          mirror.row_net: P6
  rotate: SPLIT_ROTATION
  mirror:
    ref: matrix_inner_home
    distance: SPLIT_DISTANCE
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

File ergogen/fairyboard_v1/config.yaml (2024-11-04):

meta:
  engine: 4.1.0
  version: 1.0
  author: Steven Eisinger (restive.engines)

#---------------------------------------------------------------------------------------------------
# Define unit constants
units:
  # split
  SPLIT_ROTATION: -14
  SPLIT_DISTANCE: 64*2  # measured from inter-index distance

  # column stagger
  COLUMN_PINKY_STAGGER: 2
  COLUMN_RING_STAGGER: 10.5
  COLUMN_MIDDLE_STAGGER: 3
  COLUMN_INDEX_STAGGER: -5
  COLUMN_INNER_STAGGER: -3.5

  # thumbfan common
  THUMBFAN_ROT: 0
  THUMBFAN_X: 0
  THUMBFAN_Y: -1u + COLUMN_INNER_STAGGER

  # thumbfan outer
  THUMBFAN_OUTER_ROT: 0
  THUMBFAN_OUTER_SPLAY: 0
  THUMBFAN_OUTER_X: 0
  THUMBFAN_OUTER_Y: 0

  # thumbfan middle
  THUMBFAN_MIDDLE_ROT: 0
  THUMBFAN_MIDDLE_SPLAY: -16.5
  THUMBFAN_MIDDLE_X: 0
  THUMBFAN_MIDDLE_Y: 0

  # thumbfan inner
  THUMBFAN_INNER_ROT: 0
  THUMBFAN_INNER_SPLAY: -16.5
  THUMBFAN_INNER_STAGGER: 0
  THUMBFAN_INNER_X: 0
  THUMBFAN_INNER_Y: 0

  # screw diameter
  SCREW_SIZE: 2.4
  SCREW_BORDER: 3.2

  # board parameters
  BOARD_FILLET: 1.1

  # case parameters
  BOTTOM_THICKNESS: 2
  WALL_THICKNESS: 3

  # plate parameters
  PLATE_THICKNESS: 1.5
  PLATE_EXTENSION: 0

#---------------------------------------------------------------------------------------------------
# Define key locations
#   matrix: finger matrix (excluding thumbs)
#   thumbfan: thumb keys
points:
  zones:
    matrix:
     # Fix placement on KiCAD sheet.
      anchor:
        shift: [100, -130]
      columns:
        outer:
          rows.top:
            row_net: ROW2
            mirror.row_net: ROW5
            column_net: COL1
          rows.home:
            row_net: ROW3
            mirror.row_net: ROW6
            column_net: COL1
          rows.bottom.skip: true
        pinky:
          key:
            stagger: COLUMN_PINKY_STAGGER
          rows.top:
            row_net: ROW2
            mirror.row_net: ROW5
            column_net: COL2
          rows.home:
            row_net: ROW3
            mirror.row_net: ROW6
            column_net: COL2
          rows.bottom:
            row_net: ROW4
            mirror.row_net: ROW7
            column_net: COL1
        ring:
          key:
            stagger: COLUMN_RING_STAGGER
          rows.top:
            row_net: ROW2
            mirror.row_net: ROW5
            column_net: COL3
          rows.home:
            row_net: ROW3
            mirror.row_net: ROW6
            column_net: COL3
          rows.bottom:
            row_net: ROW4
            mirror.row_net: ROW7
            column_net: COL2
        middle:
          key:
            stagger: COLUMN_MIDDLE_STAGGER
          rows.top:
            row_net: ROW2
            mirror.row_net: ROW5
            column_net: COL4
          rows.home:
            row_net: ROW3
            mirror.row_net: ROW6
            column_net: COL4
          rows.bottom:
            row_net: ROW4
            mirror.row_net: ROW7
            column_net: COL3
        index:
          key:
            stagger: COLUMN_INDEX_STAGGER
          rows.top:
            row_net: ROW1
            column_net: COL5
            mirror.column_net: COL4
          rows.home:
            row_net: ROW2
            mirror.row_net: ROW5
            column_net: COL5
          rows.bottom:
            row_net: ROW3
            mirror.row_net: ROW6
            column_net: COL5
        inner:
          key:
            stagger: COLUMN_INNER_STAGGER
          rows.top:
            row_net: ROW1
            column_net: COL6
            mirror.column_net: COL3
          rows.home:
            row_net: ROW2
            mirror.row_net: ROW5
            column_net: COL6
          rows.bottom:
            row_net: ROW3
            mirror.row_net: ROW6
            column_net: COL6
      rows:
        bottom:
        home:
        top:
    thumbfan:
      anchor:
        ref: matrix_index_bottom
        rotate: THUMBFAN_ROT
        shift: [THUMBFAN_X, THUMBFAN_Y]
      columns:
        outer:
          key:
            splay: THUMBFAN_OUTER_SPLAY
            rotate: THUMBFAN_OUTER_ROT
            shift: [THUMBFAN_OUTER_X, THUMBFAN_OUTER_Y]
            column_net: COL4
        middle:
          key:
            splay: THUMBFAN_MIDDLE_SPLAY
            rotate: THUMBFAN_MIDDLE_ROT
            origin: [-0.5u, -0.5u]
            shift: [THUMBFAN_MIDDLE_X, THUMBFAN_MIDDLE_Y]
            column_net: COL5
        inner:
          key:
            splay: THUMBFAN_INNER_SPLAY
            rotate: THUMBFAN_INNER_ROT
            stagger: THUMBFAN_INNER_STAGGER
            origin: [-0.5u, -0.5u]
            shift: [THUMBFAN_INNER_X, THUMBFAN_INNER_Y]
            column_net: COL6
      rows:
        thumb:
          row_net: ROW4
          mirror.row_net: ROW7
  rotate: SPLIT_ROTATION
  mirror:
    ref: matrix_index_home
    distance: SPLIT_DISTANCE
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

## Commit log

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2021-11-23 Changed directory structure, made second half of the keyboard, added nicenano
    [layout_cherry.dxf, shckb.sch, shockboard.kicad_pcb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]
2022-06-14 Added new kicad file format and preliminary ergogen layout
    [shockboard.kicad_pcb, shockboard.kicad_sch]
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2022-10-13 Added lots of files used for the 3d model
    [shockboard.kicad_pcb, shockboard_extrude.FCStd, shockboard_test.stl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]
2022-10-18 feat: started adjusting v0.2 layout. Reorganized some folders
    [shockboard_test.stl, shockboard_test_half.stl]
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2022-10-21 Added svg files for fab and changed to M3 screws
    [plate_bent.dxf]
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2022-11-09 fix: added shockboard_v0.3 with TODOS
    [shockboard-v0_3.yaml]
2023-07-15 fix: update v0.3 for ergogen v4
    [shockboard-v0_3_1.yaml]
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2024-02-09 feat: corrected nets for rows and columns
    [mx_cutouts.dxf, raw.dxf, shockboard.kicad_pcb]
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2024-03-10 wip: outline redesign
    [mx_cutouts.dxf, mx_plate.dxf, raw.dxf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]
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2024-03-17 feat: slightly flatter bottom and slightly tighter choc plates
    [choc_cutouts.dxf, choc_plate_mx.dxf, mx_plate.dxf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]
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2024-04-13 feat: replace ecad with the current ergogen output v0.4.0
    [choc_cutouts.dxf, choc_plate_mx.dxf, layout_cherry.dxf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]
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2024-04-14 wip: routing and fill, missing ground plane vias and silkscreen
    [shockboard.kicad_pcb]
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2024-04-16 feat: complete board with fab, no silkscreen yet
    [shockboard-B_Cu.gbl, shockboard-B_Mask.gbs, shockboard-B_Paste.gbp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]
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2024-04-20 feat: cleaned up minimal case and config a bit
    [board.dxf, case.stl, padded_board.dxf]
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2024-05-09 wip: top and bottom hipro case in openscad (missing some holes)
    [case_hipro_mx_bottom.scad, case_hipro_mx_top.scad, fillets2d.scad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]
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2024-05-11 feat: added screws, standoffs, and inserts and corrected assembly
    [assembly.scad, case_hipro_mx_bottom.scad, case_hipro_mx_top.scad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]
2024-05-11 feat: add hole in top case for promicro and screen
    [case_hipro_mx_top.scad, promicro_cutout.dxf, shockboard_v1.scad]
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2024-05-12 fix: add 1mm clearance to case hipro bottom mx
    [assembly.scad, case_hipro_mx_bottom.scad, case_hipro_mx_bottom.stl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]
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2024-05-14 feat: adjusted hipro mx case for better tolerances and correct heatset insert sizes. Added lowpro mx case.
    [assembly_hipro_mx.scad, assembly_lopro_mx.scad, case_bottom.scad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]
2024-05-15 feat: generate models and remove old fab files
    [assembly_hipro_mx.scad, assembly_lopro_mx.scad, case_hipro_mx_bottom.3mf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]
2024-05-18 feat: space for cable around board edge for nice view
    [assembly_hipro_mx.scad, case_bottom.scad, case_hipro_mx_bottom.3mf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]
2024-05-20 feat: test config for printing and overhang on bottom cases
    [case_bottom.scad, case_hipro_mx_bottom.3mf, case_hipro_mx_bottom.stl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]
2024-05-20 feat: remove unneeded parts and added split hipro case stls
    [case_hipro_mx_bottom_left.stl, case_hipro_mx_bottom_right.stl, test_part.3mf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]
2024-05-26 misc: update scad files for better support under pcb and wider thumb keywell
    [assembly_hipro_mx.scad, case_bottom.scad, case_hipro_mx_top.scad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]
2024-05-28 feat: fixes for thumb keywell and added a pcb spacer
    [assembly_hipro_mx.scad, assembly_lopro_mx.scad, keywell_mx.dxf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]
2024-06-02 feat: added internal support structure to cases and added pcb spacer
    [case_hipro_mx_bottom.3mf, case_hipro_mx_bottom.stl, case_hipro_mx_bottom_left.stl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]
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2024-06-21 feat: move footprints dir to be common between boards and generate first fairyboard
    [battery_switch_cutout.dxf, board.dxf, case_outline.dxf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]
2024-06-21 feat: modified rotation, thumb cluster, and split distance
    [battery_switch_cutout.dxf, board.dxf, case_outline.dxf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]
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2024-06-22 wip: invert choc hotswap and move diodes
    [fairyboard.kicad_pcb]
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2024-07-25 feat: remove top row and modify thumb cluster
    [battery_switch_cutout.dxf, board.dxf, case_outline.dxf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]
2024-08-05 feat: prototyping shape of fairyboard and added key position adjustments to ergogen
    [battery_switch_cutout.dxf, board.dxf, case_outline.dxf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]
2024-08-19 feat: adjust stagger on outer and inner column
    [battery_switch_cutout.dxf, board.dxf, case_outline.dxf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]
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2024-08-20 feat: remove a large blank space near board bottom
    [board.dxf, board_raw.dxf, case_outline.dxf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]
2024-08-20 feat: reverse column and row net of inverted chocs
    [board.dxf, board_raw.dxf, case_outline.dxf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]
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2024-09-25 feat: create spacerhole and move them to appropriate positions
    [fairyboard.kicad_pcb]
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2024-09-26 fix: VIK OUT instead of VIK IN
    [fairyboard.kicad_pcb]
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2024-09-28 fix: adjust bottom mounting holes
    [fairyboard.kicad_pcb]
2024-09-29 feat: increase fillet size to prevent DRC error
    [board.dxf, case_outline.dxf, fairyboard.kicad_pcb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]
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2024-10-02 feat: correct flipped silkscreen
    [fairyboard.kicad_pcb]
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2024-10-05 feat: move mounting hole for screen up and make silkscreen visible for terminal_block
    [fairyboard.kicad_pcb]
2024-10-06 misc: move labels of terminal block a bit up
    [fairyboard.kicad_pcb]
2024-10-06 misc: correct nets for all rows and columns
    [fairyboard.kicad_pcb]
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2024-10-06 misc: adjust spacer hole clearance
    [fairyboard.kicad_pcb]
2024-10-07 misc: correct pin order on mcu
    [fairyboard.kicad_pcb]
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2024-10-07 feat: simple cases (missing cutouts)
    [battery_switch_cutout.dxf, case_hipro_mx.stl, case_lowpro.stl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]
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2024-10-09 feat: minor adjustments to component placement and switch D5 for D1 as default cs pin
    [fairyboard.kicad_pcb]
2024-10-10 misc: move jst connector up and fix - character
    [config.yaml]
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2024-10-10 feat: added terminal block for extra pins and rearranged terminal block pins
    [fairyboard.kicad_pcb]
2024-10-10 feat: save and move pcb to pcbs folder
    [fairyboard.kicad_pcb]
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2024-10-13 feat: adjustments to top of pcb and silkscreen
    [fairyboard.kicad_pcb]
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2024-10-20 misc: cleanup unused pyproject and add step file
    [fairyboard.step]
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2024-10-23 feat: added some construction outlines for future cad work
    [cutouts_extension.dxf, fairyboard_v1.scad, m2_spacers.dxf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]
2024-10-24 feat: consolidate top case/plate cad and create top cases
    [cutouts_extension.dxf, top_case.scad, top_case_choc_v1.stl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]
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2024-11-02 feat: added choc v2 top case print files
    [top_case_choc_v2_left.3mf, top_case_choc_v2_right.3mf]
2024-11-03 feat: complete bottom case and top case refactor
    [bottom_case.scad, top_case.scad]
2024-11-04 feat: fillet top case and refine top and bottom case
    [bottom_case.scad, fairyboard_v1.scad, top_case.scad]
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2024-11-05 feat: added fillet utils and use on center window
    [assembly.scad, bottom_case.scad, center_window.scad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]
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2024-11-09 feat: some cutouts on top case and refined bottom case
    [assembly.scad, bottom_case.scad, center_window.scad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]
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2024-11-23 feat: create flat center window and a dxf for a plate
    [center_plate_with_terminal8_cutout.dxf, center_window.scad, center_window_flat_with_screen_terminal8_cutout.stl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]
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2024-11-24 feat: modify the center window to be lower profile and generate several versions (case and plate)
    [assembly.scad, center_plate_with_screen_terminal8_cutout.dxf, center_plate_with_screen_terminal8_cutout.stl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]
2024-12-01 feat: cleanup and fix SCUF bumpons
    [assembly.scad, bottom_case.scad, bottom_case_choc_v1_left.3mf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]
2025-03-21 misc: add split bottom case 3mf for printing
    [bottom_case_lowpro_window_mounting_left.3mf, bottom_case_lowpro_window_mounting_right.3mf]
2025-03-21 feat: added wider holes for bottom case when printing resin
    [assembly.scad, bottom_case.scad]
2025-03-21 feat: correct inserts for resin
    [bottom_case.scad]
